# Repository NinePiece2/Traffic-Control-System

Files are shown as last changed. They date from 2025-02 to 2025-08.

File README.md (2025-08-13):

# **Traffic Control System** 🚦  

## Table of Contents
- [**Traffic Control System** 🚦](#traffic-control-system-)
  - [Table of Contents](#table-of-contents)
  - [Workflow Status](#workflow-status)
  - [Introduction \& Background](#introduction--background)
    - [Background](#background)
    - [Rationale](#rationale)
    - [Scope](#scope)
  - [Design Specifications](#design-specifications)
    - [Pedestrian Detection and Safety](#pedestrian-detection-and-safety)
    - [Real-Time Video Streaming](#real-time-video-streaming)
    - [Hand Drawn Schematic of the Physical Design](#hand-drawn-schematic-of-the-physical-design)
    - [Microservice Architecture Design Diagram](#microservice-architecture-design-diagram)
    - [Early Design Mockup](#early-design-mockup)
    - [Final Design Implementation](#final-design-implementation)
      - [User Login](#user-login)
      - [Available Signals](#available-signals)
      - [Incident Reports for a Traffic Light](#incident-reports-for-a-traffic-light)
      - [Live Traffic Light](#live-traffic-light)
      - [Accounts Page](#accounts-page)
    - [Physical Design Components](#physical-design-components)
      - [PCB Design Image](#pcb-design-image)
      - [Design Assembly Render](#design-assembly-render)
      - [Design Assembly Render Video](#design-assembly-render-video)
      - [Physical Design Photo](#physical-design-photo)
  - [Installing the Microservices](#installing-the-microservices)
  - [Client Install Instructions:](#client-install-instructions)
    - [Client Debugging](#client-debugging)

## Workflow Status

| Workflow | Status |
|---|---|
| CI MVC Application | |
| CI API Application |  |
| CI Video Application |  |
| CD MVC, API, and Video Applications |  |
| Client CI Pipeline |  |

## Introduction & Background

A **smart traffic control system** designed to efficiently manage and optimize traffic flow.

### Background
In the modern day, successfully controlling urban traffic in the city is a necessity due to the ever-increasing number of vehicles and, consequently, the need for pedestrian safety.  In considering the traffic control system, what comes to mind is its ability to handle complex, changing traffic conditions, communicate clearly, and be accessible to visually impaired pedestrians. Additionally, incorporating sophisticated monitoring and control features into these systems continues to pose a technical challenge.

A frequent drawback in previous designs was the dependence on RF-link communication, which imposed limitations regarding data transmission reliability and scalability. To overcome these limitations, this project shifts to utilizing WiFi communication, providing increased flexibility, greater bandwidth, and improved compatibility with contemporary web-oriented control systems.

### Rationale
When determining the core processing unit, the Raspberry Pi was selected with the vision of being capable of employing adaptable and affordable embedded systems. Some of the benefits of the Raspberry Pi include real-time data processing, streamlined integration with cameras and sensors, and effective communication through WiFi. This makes it a perfect option for projects that need both hardware management and software interaction.

The web technologies were chosen to offer an intuitive user interface for system supervision and management. A .NET MVC website was created, incorporating Microsoft Identity Framework for secure user login, allowing the traffic system managers to have remote access to the system. As a result, supervisors can easily change parameters, manually control traffic signals, and view stored camera data such as images and videos of traffic violations. The addition of video imaging features improves the dependability of the system by allowing for future footage examination, holding violators accountable.

### Scope
The prototype created in this project tackles essential elements of traffic management by emphasizing real-time regulation and accessibility components. The system comprises:

1.	Real-Time Traffic Management: Combining magnetic reed switches and pedestrian buttons enables adaptive modification of traffic signals according to the presence of vehicles and pedestrians.
2.	Pedestrian Support: Buttons to signal a pedestrian to cross safely. Additionally, chimes at the time of safe crossing to signal the visually impaired are included.
3.	Traffic Violation Surveillance: A CMOS camera records high-quality images of traffic infractions, with video recording capabilities available for immediate processing and storage.
4.	Remote Management: A prototype website, developed using .NET MVC, allows for secure manual traffic light operations and remote observation of violation information.

This project provides a scalable solution for traffic control issues by incorporating contemporary technologies and enhancing traditional models. Future versions can upgrade the system’s capabilities to incorporate sophisticated image recognition, cloud storage, and overall traffic management across the network.

---

## Design Specifications

The Traffic Light Control System is designed to improve traffic management and pedestrian safety while addressing modern urban mobility challenges. The system provides:
-	Accessibility for Visually Impaired Pedestrians: Auditory signals inform visually impaired individuals when it is safe to cross the street.
-	Traffic Violation Detection: The Traffic Light Control System uses pressure sensors in order to detect when a vehicle crosses an intersection under a red light. It also uses a camera to take a picture of the violator's license plate, and record it for further use.
-	Remote Control and Data Access: The system uses a user friendly GUI, which, when connected to the internet, allows for monitoring the intersection at real time. Other features include recording and storing violations, and also manually adjusting the lights using an override.
-	Operation Modes: The user can change  traffic signal timings in accordance to different times of the day. this is useful for when there is an unexpected scenario, or an increase or decrease in traffic.
-	Power and Processing Requirements: A 5V power supply supports a Raspberry Pi single-board computer. The Raspberry Pi's integrated GPIO pins are used to interface with sensors, cameras, and traffic signal components, making it a very easy to use platform for this application.

### Pedestrian Detection and Safety

The SSD-MobileNetV2-FPNLite model is used to properly identify and classify pedestrians, vehicles and other objects. Pytesseract is used to extract license plates from vehicles that have commited traffic violations. For pedestrian safety, buzzers are used to sound for when there is a traffic violation detected, which is used alongside a pressure sensor. Lastly, other audio beeps are used for when a pedestrian requests to cross, and then they are sounded to make both the pedestrian and driver alerted of the shortened signal timings.

### Real-Time Video Streaming

RTMP ensures smooth video streaming from the CMOS camera to the GUI. This allows the user to be able to control traffic remotely, and make any changes necessary. They can also monitor the live intersection, and look at recorded traffic violations, should they deem necessary.

### Hand Drawn Schematic of the Physical Design

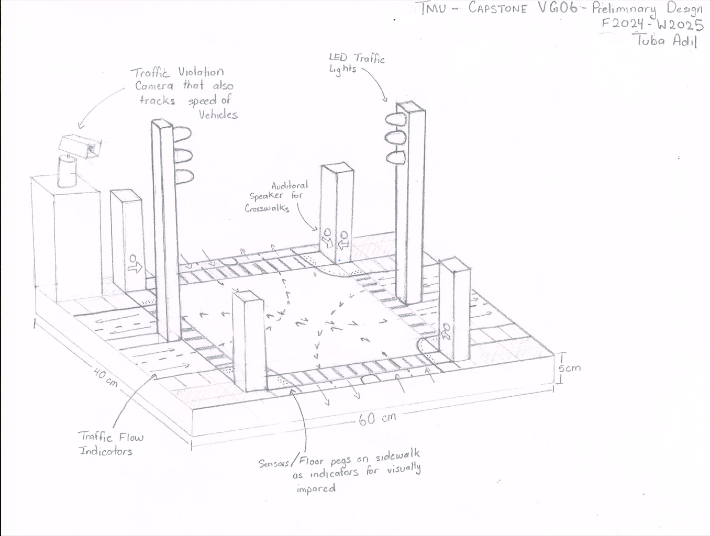
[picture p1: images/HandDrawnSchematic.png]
[](images/HandDrawnSchematic.png)

### Microservice Architecture Design Diagram

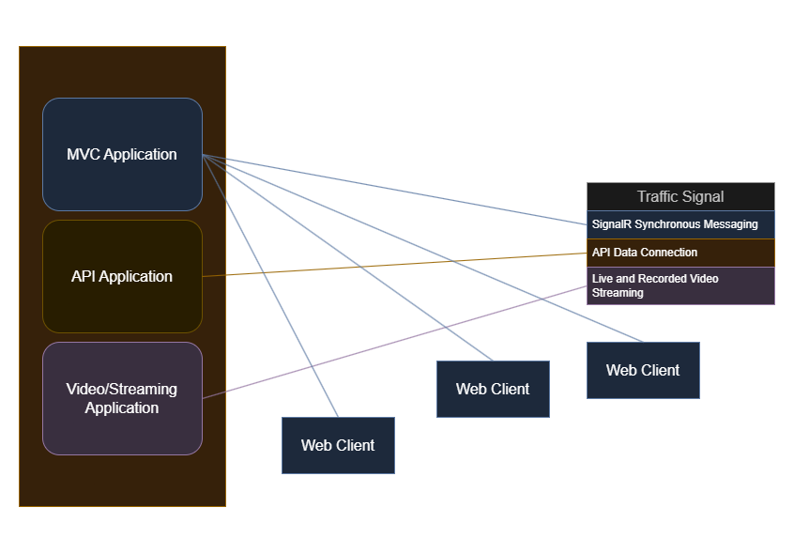
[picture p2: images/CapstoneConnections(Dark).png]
[](images/CapstoneConnections(Dark).png)

### Early Design Mockup

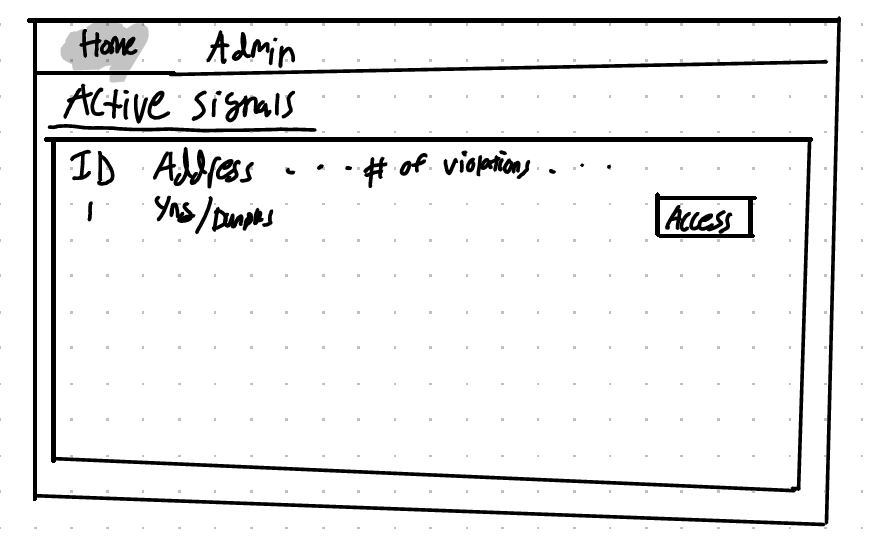
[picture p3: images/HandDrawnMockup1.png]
[](images/HandDrawnMockup1.png)
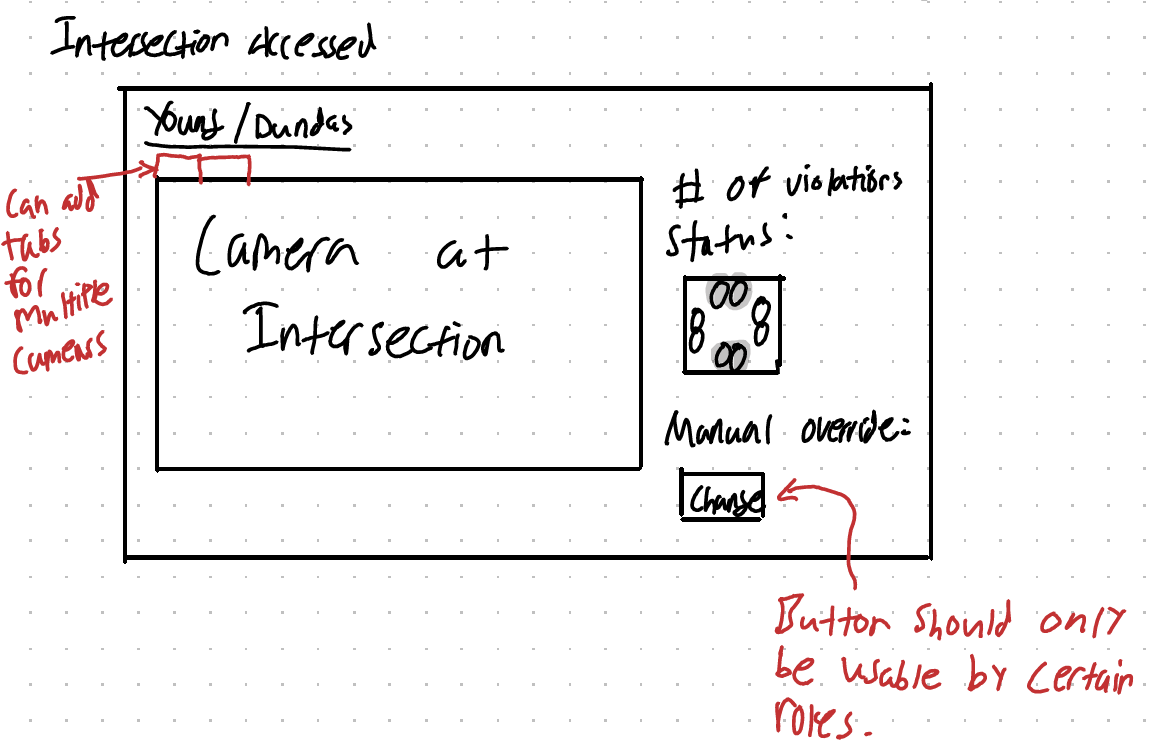
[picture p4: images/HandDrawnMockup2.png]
[](images/HandDrawnMockup2.png)

### Final Design Implementation

#### User Login 

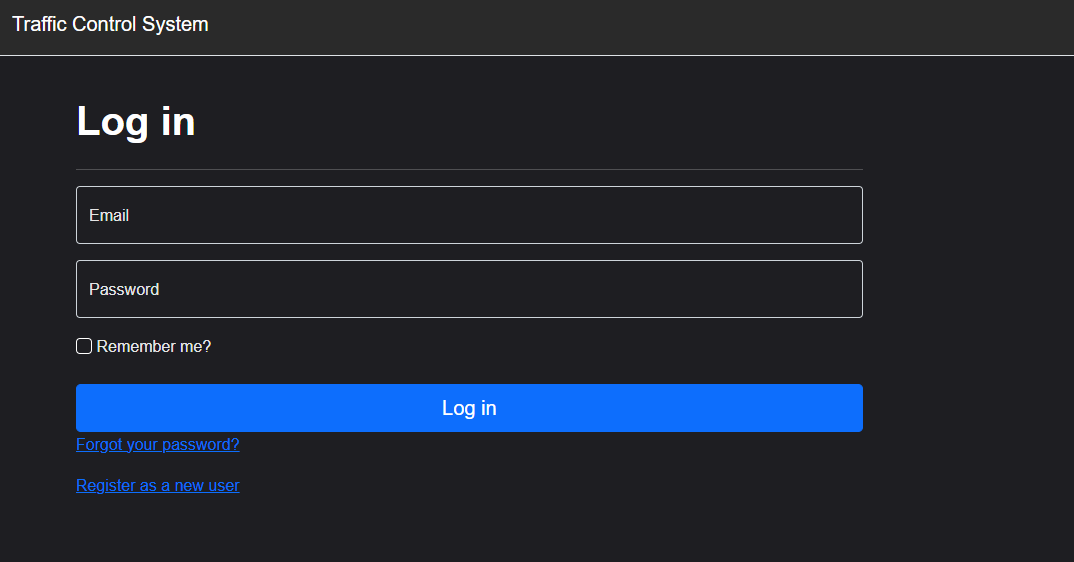
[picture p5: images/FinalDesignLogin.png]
[](images/FinalDesignLogin.png)

#### Available Signals

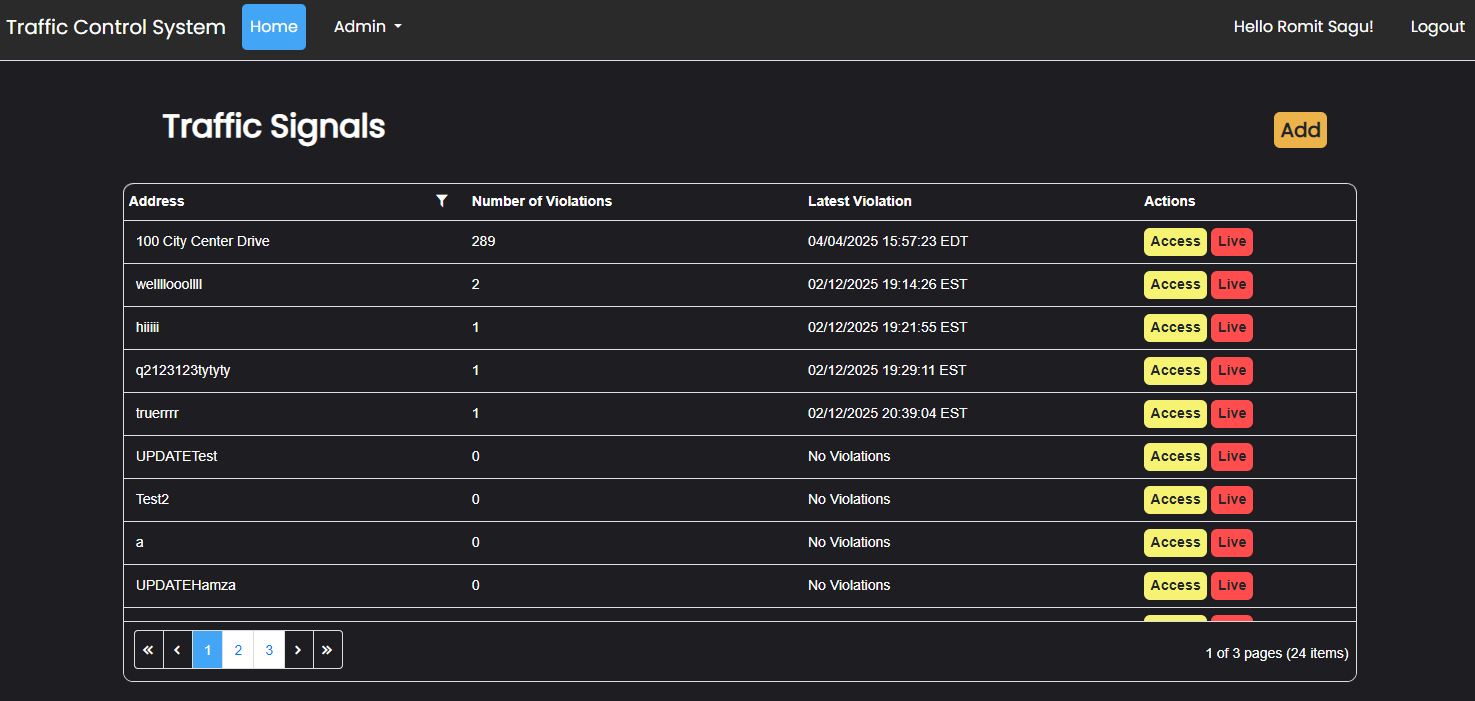
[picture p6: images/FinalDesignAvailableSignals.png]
[](images/FinalDesignAvailableSignals.png)

#### Incident Reports for a Traffic Light

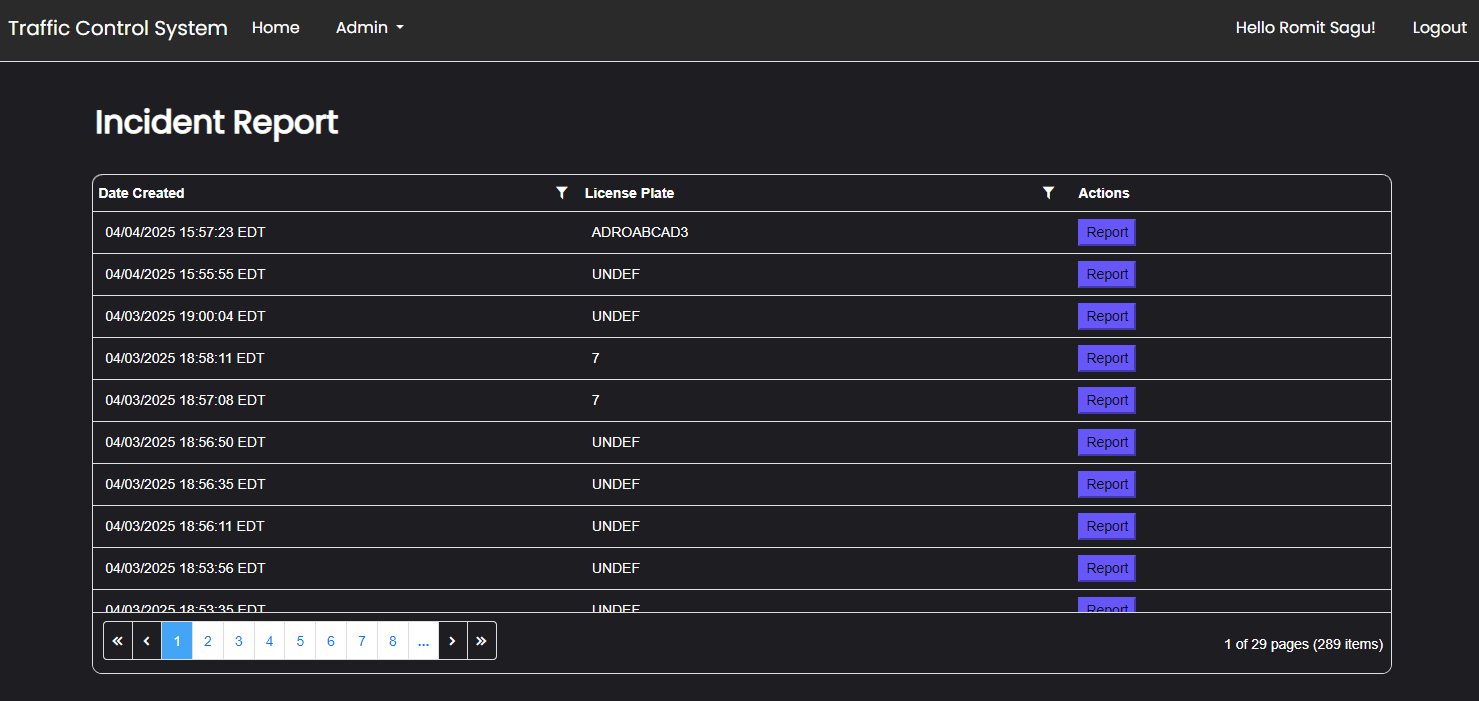
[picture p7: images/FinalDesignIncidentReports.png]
[](images/FinalDesignIncidentReports.png)

#### Live Traffic Light

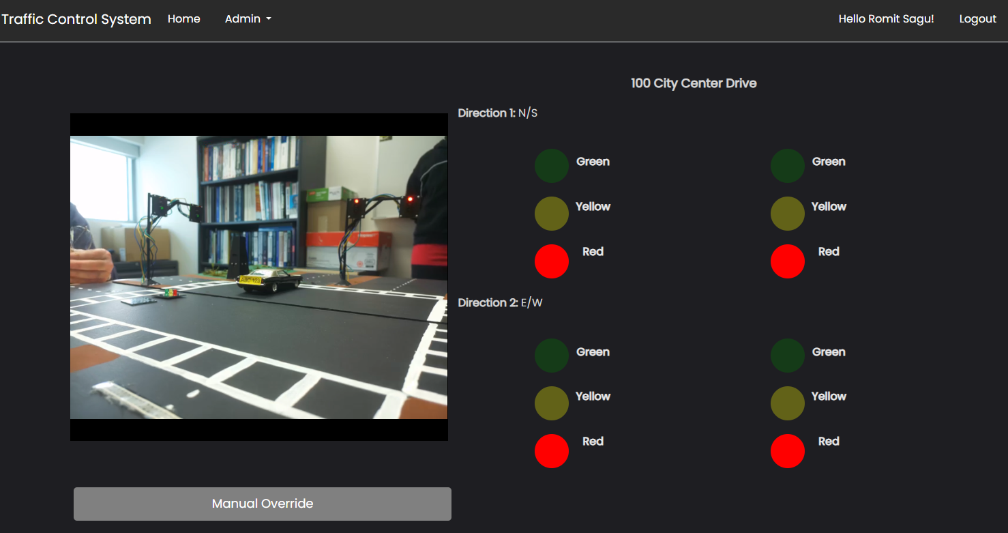
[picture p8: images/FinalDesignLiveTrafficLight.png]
[](images/FinalDesignLiveTrafficLight.png)

#### Accounts Page

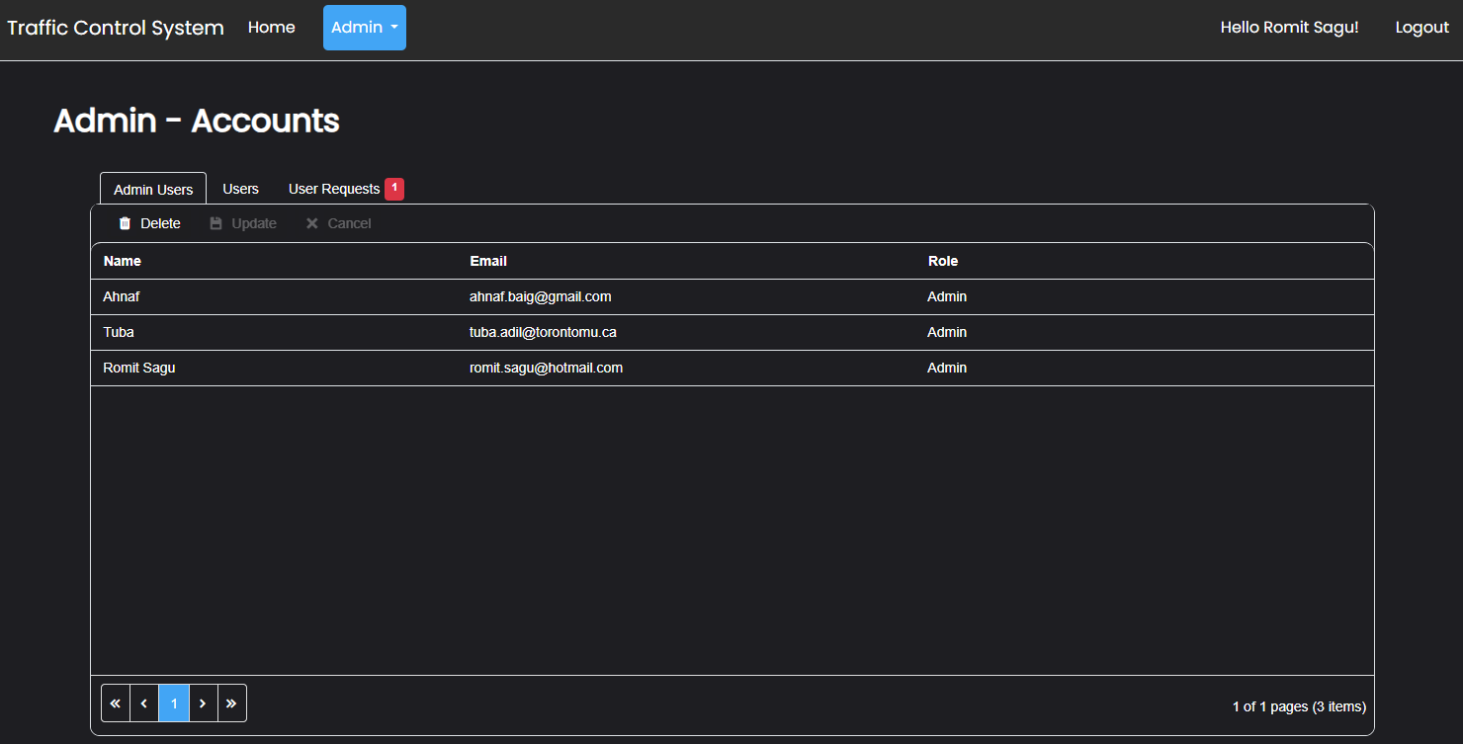
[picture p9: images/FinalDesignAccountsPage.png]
[](images/FinalDesignAccountsPage.png)

### Physical Design Components

To make the physical design look cohesive, a custom Printed Circut Board was designed and manufactured to replicate an actual traffic light. The CAD and PCB design files are availabe <a href="https://github.com/NinePiece2/Traffic-Control-System/tree/master/CADFiles" target="_blank" rel="noopener noreferrer">here</a>. The CAD files were designed using Fusion 360 and the PCB was created using KiCAD.

#### PCB Design Image

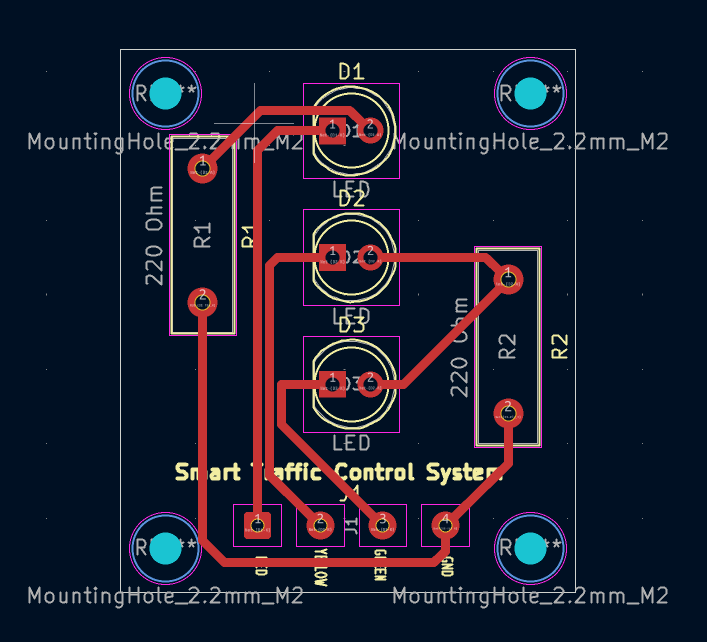
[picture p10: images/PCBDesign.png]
[](images/PCBDesign.png)

#### Design Assembly Render

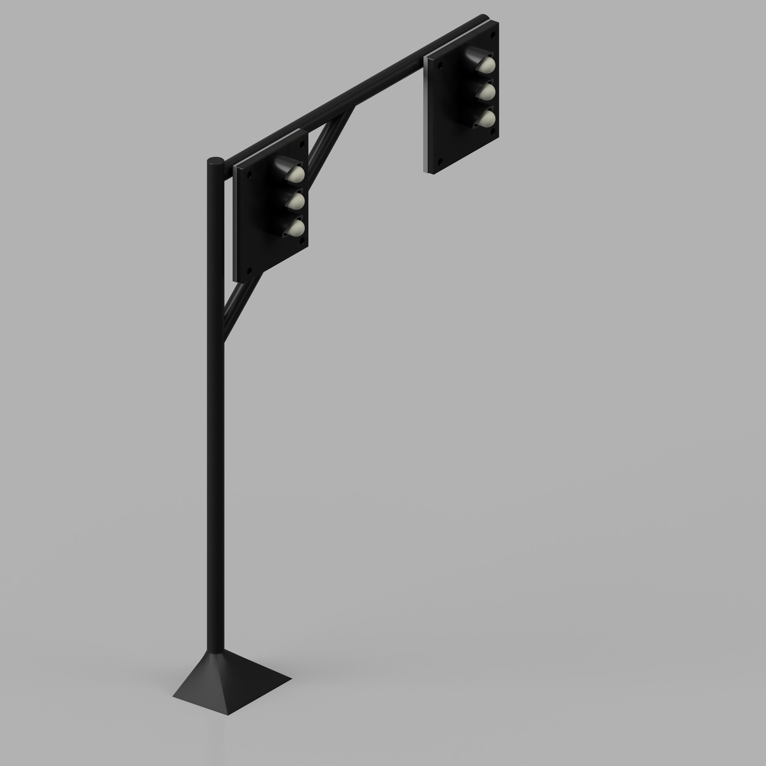
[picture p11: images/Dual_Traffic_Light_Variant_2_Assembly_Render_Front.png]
[](images/Dual_Traffic_Light_Variant_2_Assembly_Render_Front.png)

#### Design Assembly Render Video

<!-- <video src="images/Dual_Traffic_Light_Variant_2_Assembly_Render_v3_Animation_2.mp4" autoplay muted loop playsinline width="800"></video> -->

Click to download the video:

<a href="https://github.com/NinePiece2/Traffic-Control-System/raw/refs/heads/master/images/Dual_Traffic_Light_Variant_2_Assembly_Render_v3_Animation_2.mp4">
  Video Preview
</a>

#### Physical Design Photo

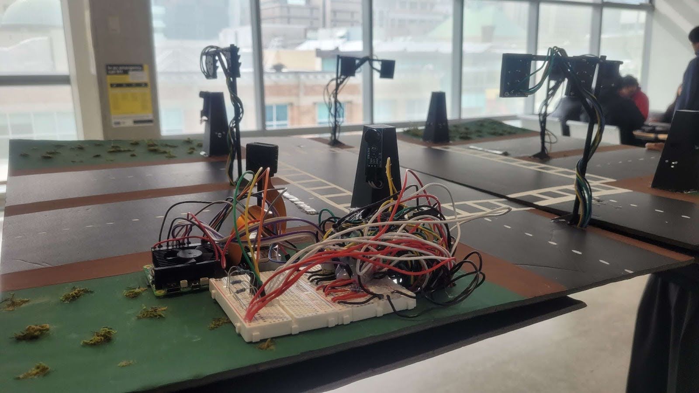
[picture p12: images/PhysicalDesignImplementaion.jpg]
[](images/PhysicalDesignImplementaion.jpg)

---

## Installing the Microservices

Use ```docker-compose.yml``` and change the variables where applicable to allow the microservices to communicate with each other. Use SSL certificates as required. The `JWT_KEY` should be the same on all the services.

```docker-compose.yml```:

```yml
version: '3.8'

services:
  mvc:
    image: ninepiece2/traffic-control-system:mvc
    container_name: Traffic-Control-System
    ports:
      - "8443:8443"
    volumes:
      - /root/certs:/https:ro
    environment:
      - ASPNETCORE_URLS=https://*:8443;http://*:8080
      - ASPNETCORE_Kestrel__Certificates__Default__Path=/https/ssl.crt
      - ASPNETCORE_Kestrel__Certificates__Default__KeyPath=/https/ssl.key
      - ASPNETCORE_ENVIRONMENT=${ASPNETCORE_ENVIRONMENT}
      - SyncfusionLicense=${SyncfusionLicense}
      - BaseUrl=https://trafficcontrolsystem.romitsagu.com
      - VideoServiceURL=https://stream-trafficcontrolsystem.romitsagu.com
      - StreamServiceURL=https://stream1-trafficcontrolsystem.romitsagu.com
      - APIURL=https://api-trafficcontrolsystem.romitsagu.com
      - API_KEY=${JWT_Key}
    command: ["dotnet", "Traffic-Control-System.dll"]
    restart: always
  
  api:
    image: ninepiece2/traffic-control-system:api
    container_name: Traffic-Control-System-API
    ports:
      - "8445:8445"
    volumes:
      - /root/certs:/https:ro
    environment:
      - ASPNETCORE_URLS=https://*:8445;http://*:8080
      - ASPNETCORE_Kestrel__Certificates__Default__Path=/https/ssl.crt
      - ASPNETCORE_Kestrel__Certificates__Default__KeyPath=/https/ssl.key
      - ASPNETCORE_ENVIRONMENT=${ASPNETCORE_ENVIRONMENT}
      - StreamServiceURL=https://stream1-trafficcontrolsystem.romitsagu.com
      - JWT:Issuer=https://api-trafficcontrolsystem.romitsagu.com
      - JWT:Audience=https://api-trafficcontrolsystem.romitsagu.com
      - JWT:Key=${JWT_Key}
    command: ["dotnet", "Traffic-Control-System-API.dll"]
    restart: always

  video:
    image: ninepiece2/traffic-control-system:video
    container_name: Traffic-Control-System-Video
    ports:
      - "1935:1935"
      - "8446:8446"
    volumes:
      - /root/certs:/https:ro
    environment:
      - ASPNETCORE_URLS=https://*:8446;http://*:8080
      - ASPNETCORE_Kestrel__Certificates__Default__Path=/https/ssl.crt
      - ASPNETCORE_Kestrel__Certificates__Default__KeyPath=/https/ssl.key
      - ASPNETCORE_ENVIRONMENT=${ASPNETCORE_ENVIRONMENT}
      - JWT:Issuer=https://stream-trafficcontrolsystem.romitsagu.com
      - JWT:Audience=https://stream-trafficcontrolsystem.romitsagu.com
      - JWT:Key=${JWT_Key}
    command: ["dotnet", "Traffic-Control-System-Video.dll"]
    restart: always
```

## Client Install Instructions:

Run the following on a Raspberry Pi 5. This will install docker, docker compose and create a new folder with the ```docker-compose.yml``` file and a config file located under ```config/config.json```. After creating a new traffic light in the MVC application enter the outputed config values in the ```config/config.json``` file. Follow the instructions and run ```docker compose up -d```/```docker-compose up -d``` within the created folder to run the container and traffic light application.

```sh
curl -O https://raw.githubusercontent.com/NinePiece2/Traffic-Control-System/refs/heads/master/RaspPiPythonScripts/installer.sh && sudo bash installer.sh
```

### Client Debugging

If you enconuter:

```sh
OSError: [Errno 12] Cannot allocate memory
```

Go to the file `sudo nano /boot/firmware/config.txt`

Locate the line `dtoverlay=vc4-fkms-v3d` and change it to `dtoverlay=vc4-fkms-v3d,cma-256` and Restart the Raspberry Pi.

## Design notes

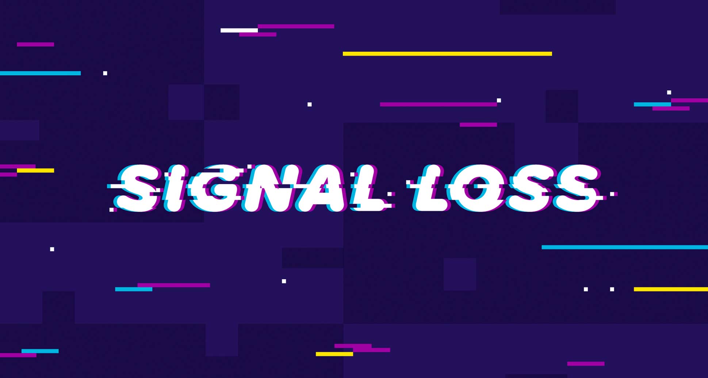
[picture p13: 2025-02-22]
Traffic-Control-System/wwwroot/Images/error-placeholder.jpg

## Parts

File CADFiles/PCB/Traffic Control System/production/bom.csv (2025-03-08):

Designator | Footprint | Quantity | Value | LCSC Part #
D1, D2, D3 | LED_D5.0mm_Clear | 3 | LED
J1 | SolderWire-0.25sqmm_1x04_P4.2mm_D0.65mm_OD1.7mm | 1 | Conn_01x04_Pin
R1, R2 | R_Box_L13.0mm_W4.0mm_P9.00mm | 2 | 220 Ohm

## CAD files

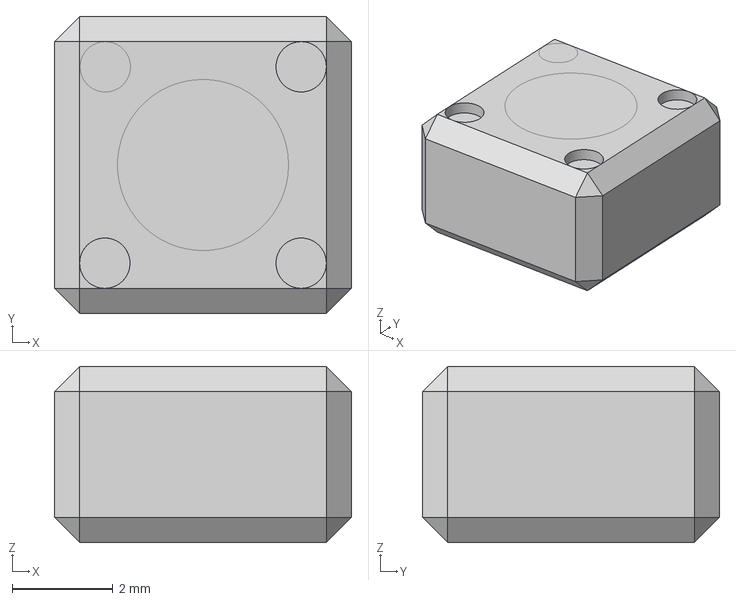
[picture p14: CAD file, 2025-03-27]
CADFiles/3D Printed Mounts/Traffic Light Button Hole v4.step
5.90 x 5.90 x 3.50 mm

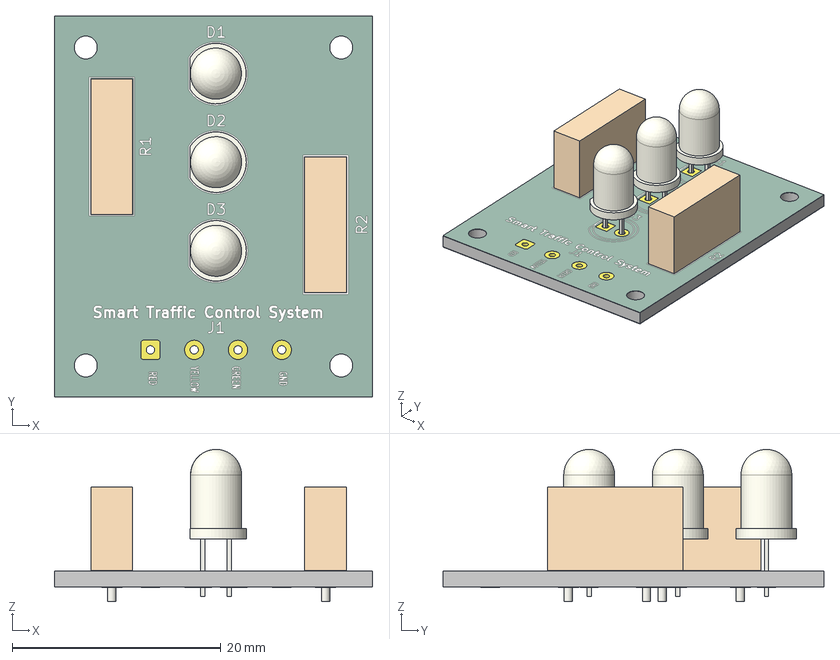
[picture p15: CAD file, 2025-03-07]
CADFiles/PCB/Traffic Control System/Traffic Control System.step
30.5 x 36.5 x 14.6 mm
R_Box_L13.0mm_W4.0mm_P9.00mm x 2
LED_D5.0mm_Clear x 3
Traffic Control System_copper
Traffic Control System_silkscreen
Traffic Control System_soldermask
Traffic Control System_PCB

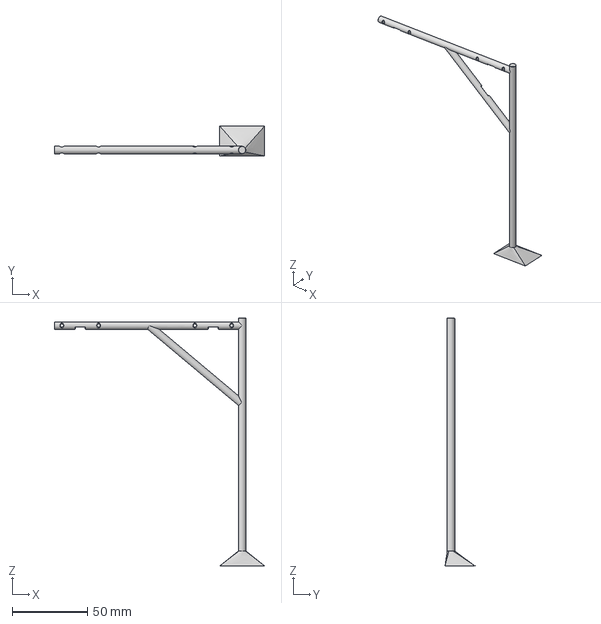
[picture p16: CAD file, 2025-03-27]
CADFiles/3D Printed Mounts/Dual Traffic Light Variant 2 v9.step
140.0 x 20.0 x 165.0 mm

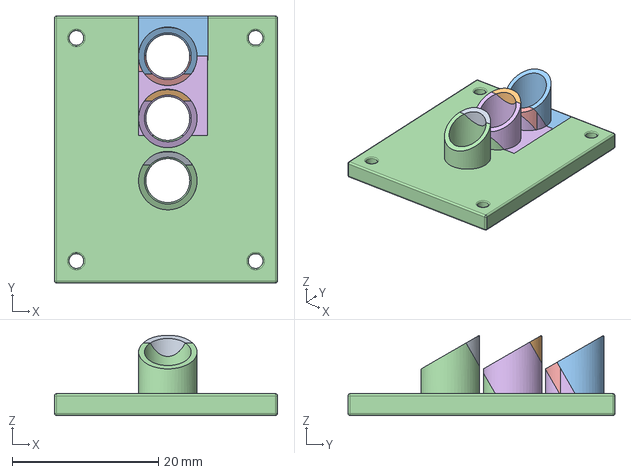
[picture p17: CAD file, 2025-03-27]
CADFiles/3D Printed Mounts/Traffic Light Cover v9.step
30.5 x 36.5 x 11.0 mm

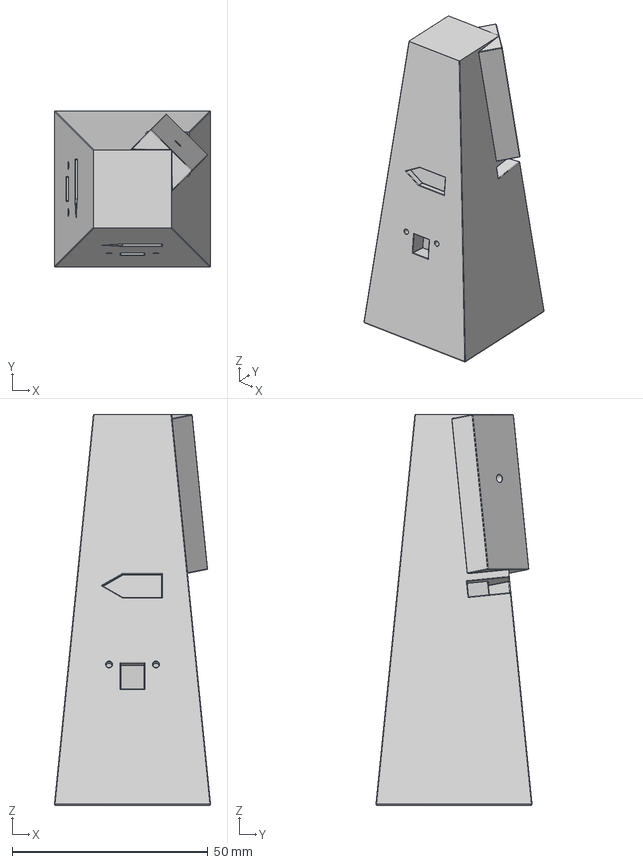
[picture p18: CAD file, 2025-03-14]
CADFiles/3D Printed Mounts/Button and Buzzer stand.step
39.9 x 39.9 x 100.0 mm

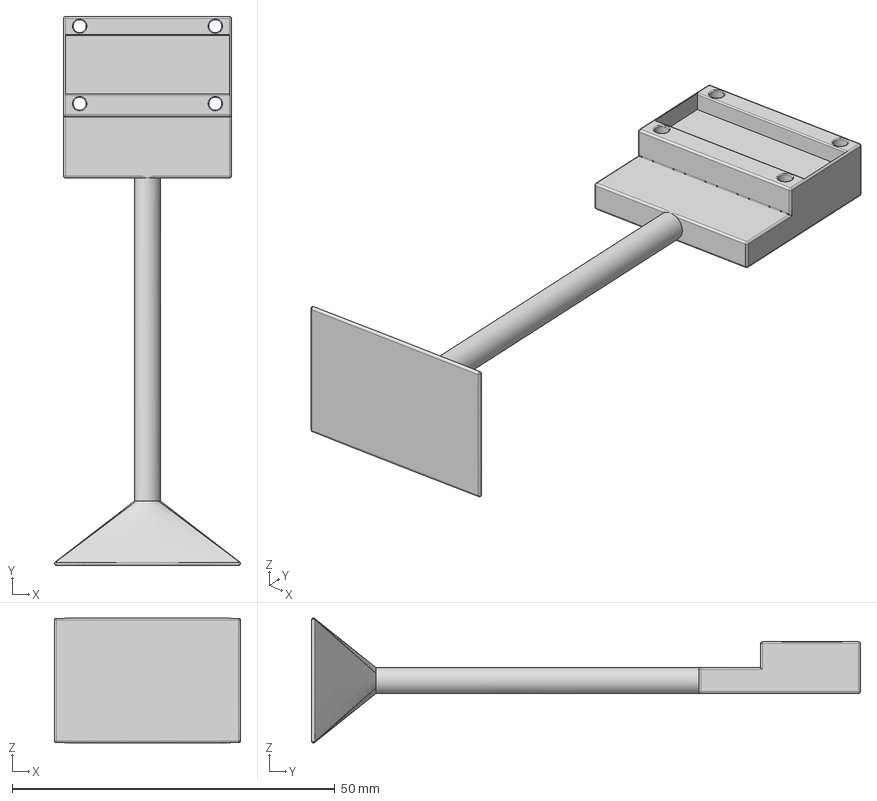
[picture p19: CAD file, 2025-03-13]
CADFiles/3D Printed Mounts/Pi AI Camera Stand.step
28.8 x 85.0 x 19.3 mm

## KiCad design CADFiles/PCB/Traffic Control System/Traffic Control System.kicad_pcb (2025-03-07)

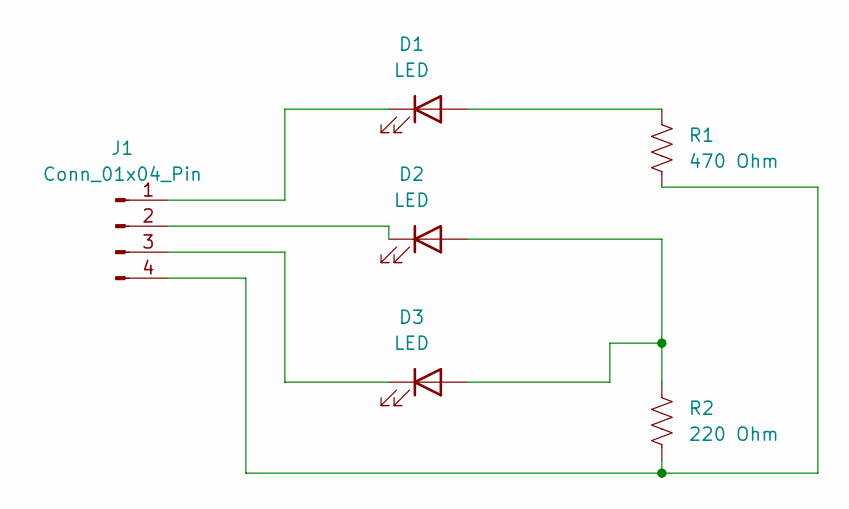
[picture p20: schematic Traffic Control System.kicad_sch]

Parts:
D1, D2, D3: LED; LED_D5.0mm_Clear
J1: Conn_01x04_Pin; SolderWire-0.25sqmm_1x04_P4.2mm_D0.65mm_OD1.7mm
R1: 470 Ohm; R_Box_L13.0mm_W4.0mm_P9.00mm
R2: 220 Ohm; R_Box_L13.0mm_W4.0mm_P9.00mm

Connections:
unnamed: D1.2 (A), R1.1
unnamed: D1.1 (K), J1.1
unnamed: D2.2 (A), D3.2 (A), R2.1
unnamed: D2.1 (K), J1.2
unnamed: D3.1 (K), J1.3
unnamed: J1.4, R1.2, R2.2

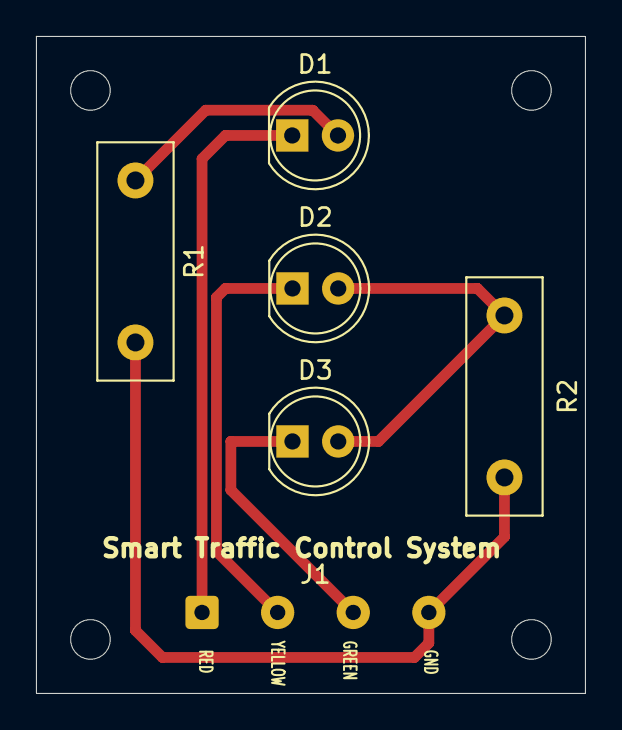
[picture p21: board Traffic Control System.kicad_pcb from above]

Board: 2 copper layers, 30.5 x 36.5 mm, 6 parts (0 on the bottom side), 6 nets.

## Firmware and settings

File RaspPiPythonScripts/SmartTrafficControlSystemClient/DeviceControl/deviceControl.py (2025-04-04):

import os
import platform
import time
import threading
from gpiozero import LED, Button, PWMOutputDevice
import Config.config as config
import threading

# Only set the mock pin factory if the OS is not Linux
if platform.system() != "Linux":
    os.environ["GPIOZERO_PIN_FACTORY"] = "mock"
    print("DEV DETECTED: Using mock pin factory")
else:
    print("PROD: Using RPi pin factory")


class TrafficLightController:
    def __init__(self, signalR_client_callback, incident_detected_callback):
        """
        Initializes the traffic light controller with configuration.
        """
        self.interrupt_flag = threading.Event()
        self.signalR_client_callback = signalR_client_callback
        self.incident_detected_callback = incident_detected_callback

        # Define traffic lights for two directions
        self.traffic_lights = {
            "light_dir_1": {"red": LED(17), "yellow": LED(27), "green": LED(22)},
            "light_dir_2": {"red": LED(23), "yellow": LED(24), "green": LED(25)}
        }

        # Define pedestrian buttons (One per direction)
        self.pedestrian_buttons = {
            "light_dir_1": Button(18),  # GPIO 18 for direction 1
            "light_dir_2": Button(19)   # GPIO 19 for direction 2
        }

        # Attach event listeners for pedestrian buttons
        self.pedestrian_buttons["light_dir_1"].when_pressed = lambda: self.pedestrian_pressed("light_dir_1")
        self.pedestrian_buttons["light_dir_2"].when_pressed = lambda: self.pedestrian_pressed("light_dir_2")

        self.pedestrian_button_pressed = {
            "light_dir_1": False,
            "light_dir_2": False
        }

        # Define passive buzzers on pins 12, 13, 14, and 15 using PWMOutputDevice (Buzzers need to be attached to 3.3v)
        self.buzzers = {
            "buzzer1": PWMOutputDevice(12, active_high=False),
            # "buzzer2": PWMOutputDevice(13, active_high=False),
            # "buzzer3": PWMOutputDevice(14, active_high=False),
            # "buzzer4": PWMOutputDevice(15, active_high=False)
        }

        self.pressure_sensors = {
            "light_dir_1_sensor1": Button(5),
            "light_dir_1_sensor2": Button(6),
            "light_dir_2_sensor1": Button(13),
            "light_dir_2_sensor2": Button(16)
        }

        self.last_pressure_detected = {
            "light_dir_1_sensor1": time.mktime((1970, 1, 1, 0, 0, 0, 0, 1, -1)),
            "light_dir_1_sensor2": time.mktime((1970, 1, 1, 0, 0, 0, 0, 1, -1)),
            "light_dir_2_sensor1": time.mktime((1970, 1, 1, 0, 0, 0, 0, 1, -1)),
            "light_dir_2_sensor2": time.mktime((1970, 1, 1, 0, 0, 0, 0, 1, -1))
        }

        self.last_pressure_release_detected = {
            "light_dir_1_sensor1": time.mktime((1970, 1, 1, 0, 0, 0, 0, 1, -1)),
            "light_dir_1_sensor2": time.mktime((1970, 1, 1, 0, 0, 0, 0, 1, -1)),
            "light_dir_2_sensor1": time.mktime((1970, 1, 1, 0, 0, 0, 0, 1, -1)),
            "light_dir_2_sensor2": time.mktime((1970, 1, 1, 0, 0, 0, 0, 1, -1))
        }

        self.pressure_sensors["light_dir_1_sensor1"].when_released = lambda: self.pressure_sensor_pressed("light_dir_1_sensor1")
        self.pressure_sensors["light_dir_1_sensor2"].when_released = lambda: self.pressure_sensor_pressed("light_dir_1_sensor2")
        self.pressure_sensors["light_dir_2_sensor1"].when_released = lambda: self.pressure_sensor_pressed("light_dir_2_sensor1")
        self.pressure_sensors["light_dir_2_sensor2"].when_released = lambda: self.pressure_sensor_pressed("light_dir_2_sensor2")

        self.pressure_sensors["light_dir_1_sensor1"].when_held = lambda: self.pressure_sensor_released("light_dir_1_sensor1")
        self.pressure_sensors["light_dir_1_sensor2"].when_held = lambda: self.pressure_sensor_released("light_dir_1_sensor2")
        self.pressure_sensors["light_dir_2_sensor1"].when_held = lambda: self.pressure_sensor_released("light_dir_2_sensor1")
        self.pressure_sensors["light_dir_2_sensor2"].when_held = lambda: self.pressure_sensor_released("light_dir_2_sensor2")

        # Track active light (default direction)
        self.active_light = "light_dir_1"

    def pedestrian_pressed(self, light_name):
        """Handles pedestrian button press event for the given direction."""
        self.pedestrian_button_pressed[light_name] = True
    
    def pressure_sensor_pressed(self, sensor_name):
        """Handles pressure sensor press event for the given sensor."""
        self.last_pressure_detected[sensor_name] = time.time()
        #print(f"Pressure sensor {sensor_name} pressed {time.strftime('%Y-%m-%d %H:%M:%S', time.localtime(time.time()))}.")

    def pressure_sensor_released(self, sensor_name):
        """Handles pressure sensor release event for the given sensor."""
        self.last_pressure_release_detected[sensor_name] = time.time()
        #print(f"Pressure sensor {sensor_name} released {time.strftime('%Y-%m-%d %H:%M:%S', time.localtime(time.time()))}.")

    def update_config(self):
        """Updates the config dynamically and interrupts the current cycle."""
        self.interrupt_flag.set()

    def manual_override(self):
        """Triggers a manual override, stopping the current cycle immediately."""
        self.interrupt_flag.set()

    def switch_light(self, light_name, color):
        """Controls the lights (green, yellow, red) based on the given color."""
        light = self.traffic_lights[light_name]
        if color == "green":
            light["red"].off()
            light["yellow"].off()
            light["green"].on()
        elif color == "yellow":
            light["green"].off()
            light["yellow"].on()
            light["red"].off()
        elif color == "red":
            light["yellow"].off()
            light["red"].on()
            light["green"].off()
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

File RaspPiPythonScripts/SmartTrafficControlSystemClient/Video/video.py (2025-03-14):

import cv2
import subprocess
import threading
import time
from collections import deque
import requests
import Config.config as config
from jwt.exceptions import DecodeError
from datetime import datetime, timezone
import urllib.parse
import jwt
import platform
import numpy as np
import pytesseract  # For OCR
import re
import os
# Optional: if Tesseract is not in your PATH, set the tesseract_cmd
# pytesseract.pytesseract.tesseract_cmd = r"/usr/bin/tesseract"  # Adjust as needed

# Attempt to import Picamera2 and IMX500-related modules on Linux
try:
    if platform.system() == 'Linux':
        from picamera2 import Picamera2, MappedArray
        try:
            from picamera2.devices import IMX500
            from picamera2.devices.imx500 import NetworkIntrinsics, postprocess_nanodet_detection
        except ImportError:
            IMX500 = None
except ImportError:
    pass

# Global variable for detections
last_detections = []

# ----- IMX500 Object Detection Helpers -----
class Detection:
    def __init__(self, coords, category, conf, metadata, picam2, imx500_obj):
        """Stores the detection bounding box, category and confidence.
           Uses the imx500 helper to convert raw coordinates into pixel coordinates.
        """
        self.category = category
        self.conf = conf
        # Convert inference coordinates into pixel coordinates on the output image
        self.box = imx500_obj.convert_inference_coords(coords, metadata, picam2)

def parse_detections(metadata, picam2, imx500_obj, threshold, iou, max_detections):
    """Parses the raw outputs from the IMX500 detector into Detection objects."""
    global last_detections
    intrinsics = imx500_obj.network_intrinsics
    bbox_normalization = getattr(intrinsics, 'bbox_normalization', False)
    bbox_order = getattr(intrinsics, 'bbox_order', 'yx')  # default order
    np_outputs = imx500_obj.get_outputs(metadata, add_batch=True)
    input_w, input_h = imx500_obj.get_input_size()
    if np_outputs is None:
        return last_detections
    # Use nanodet postprocessing if specified
    if getattr(intrinsics, 'postprocess', None) == "nanodet":
        boxes, scores, classes = postprocess_nanodet_detection(
            outputs=np_outputs[0],
            conf=threshold,
            iou_thres=iou,
            max_out_dets=max_detections
        )[0]
        from picamera2.devices.imx500.postprocess import scale_boxes
        boxes = scale_boxes(boxes, 1, 1, input_h, input_w, False, False)
    else:
        boxes, scores, classes = np_outputs[0][0], np_outputs[1][0], np_outputs[2][0]
        if bbox_normalization:
            boxes = boxes / input_h
        if bbox_order == "xy":
            boxes = boxes[:, [1, 0, 3, 2]]
        boxes = np.array_split(boxes, 4, axis=1)
        boxes = list(zip(*boxes))
    detections = [
        Detection(box, int(category), float(score), metadata, picam2, imx500_obj)
        for box, score, category in zip(boxes, scores, classes)
        if score > threshold
    ]
    last_detections = detections
    return detections

def get_labels(intrinsics):
    """Returns a list of labels from intrinsics. Falls back to a default file if needed."""
    labels = intrinsics.labels
    if labels is None:
        try:
            with open("assets/coco_labels.txt", "r") as f:
                labels = f.read().splitlines()
        except Exception as e:
            print("Error loading default labels:", e)
            labels = []
    return labels

def recognize_license_plate(car_roi):
    """
    Given a region-of-interest (ROI) containing a car,
    locate and OCR the license plate assuming it has a YELLOW background.
    """
    # Convert the ROI to HSV color space
    hsv = cv2.cvtColor(car_roi, cv2.COLOR_BGR2HSV)

    # Define HSV range for yellow plates (tweak values as needed)
    lower_yellow = np.array([20, 100, 100], dtype=np.uint8)
    upper_yellow = np.array([35, 255, 255], dtype=np.uint8)
    
    # Create a mask that isolates only yellow regions
    mask = cv2.inRange(hsv, lower_yellow, upper_yellow)

    # Optional: Clean up the mask using morphological operations
    kernel = cv2.getStructuringElement(cv2.MORPH_RECT, (3, 3))
    mask = cv2.erode(mask, kernel, iterations=1)
    mask = cv2.dilate(mask, kernel, iterations=1)
    
    # Find contours in the mask
    contours, _ = cv2.findContours(mask, cv2.RETR_EXTERNAL, cv2.CHAIN_APPROX_SIMPLE)
    if not contours:
        return None, None

    # Sort contours by area (largest first)
    contours = sorted(contours, key=cv2.contourArea, reverse=True)
    
    # We�ll iterate through the biggest contours to find something
    # that looks like a plate by aspect ratio, etc.
    plate_candidate = None
    plate_bbox = None
    
    for c in contours:
        x, y, w, h = cv2.boundingRect(c)
        area = w * h
        aspect_ratio = w / float(h + 1e-5)  # avoid divide-by-zero
        # Heuristic checks (tweak thresholds for your plate shape/size)
        if area > 500:  # minimum area
            # For typical rectangular plates, aspect ratio often 2�5 wide
            if 2 < aspect_ratio < 6:  
                plate_candidate = car_roi[y:y+h, x:x+w]
                plate_bbox = (x, y, w, h)
                break  # pick the first (largest) plausible region
    
    if plate_candidate is None:
        return None, None

    # ---- Preprocess the plate region for OCR ----
    # Convert to grayscale
    gray_plate = cv2.cvtColor(plate_candidate, cv2.COLOR_BGR2GRAY)

    # Upscale to enhance details
    gray_plate = cv2.resize(gray_plate, None, fx=3, fy=3, interpolation=cv2.INTER_CUBIC)

    # Try adaptive threshold
    gray_plate = cv2.adaptiveThreshold(
        gray_plate, 255,
        cv2.ADAPTIVE_THRESH_GAUSSIAN_C,
        cv2.THRESH_BINARY,
        11, 2
    )

    # Dilation to help join character segments
    gray_plate = cv2.dilate(gray_plate, kernel, iterations=1)

    # OCR with Tesseract
    config_tesseract = "--oem 3 --psm 6 -c tessedit_char_whitelist=ABCDEFGHIJKLMNOPQRSTUVWXYZ0123456789"
    text = pytesseract.image_to_string(gray_plate, config=config_tesseract).strip()

    # Clean up the OCR result: remove extra whitespace, uppercase
    text = "".join(text.split()).upper()

    return text, plate_bbox
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

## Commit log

2024-10-09 Add PowerSettings
2024-10-27 try to fix framerate
2024-10-27 Try to fix framerate issues
2025-01-31 Try to fix webcam issue
    [video.py]
2025-01-31 Try to fix FFMpeg issue
    [video.py]
2025-02-02 Small Update [skip ci]
    [video.py]
2025-02-17 Add YOLO
    [yolov3-tiny.cfg]
2025-02-17 Add IMX500 Object Detection and Test CI
    [yolov3-tiny.cfg]
2025-02-17 Fix video format issue [skip ci]
    [video.py]
2025-02-18 Add License Plate Detection
2025-02-18 Impove License Plate Detection
2025-02-18 Fix Video Framerate issue [skip ci]
    [video.py]
2025-02-19 Add Filtering to Index
2025-02-19 Add Filtering and Sorting to Index Table
2025-03-06 Add PCB Files
    [Traffic Control System-B_Cu.gbr, Traffic Control System-B_Mask.gbr, Traffic Control System-B_Paste.gbr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]
2025-03-06 Add Gerber Output Files
    [Traffic Control System.kicad_pcb]
2025-03-07 Update PCB
    [Traffic Control System-B_Cu.gbr, Traffic Control System-B_Mask.gbr, Traffic Control System-B_Paste.gbr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]
2025-03-07 Add Traffic Light Stand .step files
    [Traffic Light Stand v6.step, Traffic Light Stand with 2 Lights v9.step]
2025-03-08 Add final PCB Fabrication Files
    [Traffic Control System-B_Cu.gbr, Traffic Control System-B_Mask.gbr, Traffic Control System-B_Paste.gbr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]
2025-03-10 Client Changes [skip ci]
    [deviceControl.py]
2025-03-10 Update Device Control [skip ci]
    [deviceControl.py]
2025-03-10 Fix Colour Case Issue
2025-03-10 Add Buzzers and Revise Buttons [skip ci]
    [deviceControl.py]
2025-03-10 Update Pedestrian Buttons [skip ci]
    [deviceControl.py]
2025-03-10 Set Duy Cycle to 20% [skip ci]
    [deviceControl.py]
2025-03-10 Fix code issues [skip ci]
    [deviceControl.py]
2025-03-10 Update Buzzer and Pedestrian Logic [skip ci]
    [deviceControl.py]
2025-03-11 Improve Buzzer Initialization [skip ci]
    [deviceControl.py]
2025-03-11 Improve Buzzer Timings [skip ci]
    [deviceControl.py]
2025-03-11 Add Button and Buzzer Stand
    [Button and Buzzer stand v10.step]
2025-03-11 Add Pi AI Camera Mount
    [Pi AI Camera Stand v3.step]
2025-03-12 Update CAD Files
    [Button and Buzzer stand v10.step, Button and Buzzer stand.step, Pi AI Camera Stand v3.step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]
2025-03-13 Small Updates [skip ci]
    [Pi AI Camera Stand.step]
2025-03-14 Add pressure sensing [skip ci]
    [deviceControl.py]
2025-03-14 Fix double pin issue [skip ci]
    [deviceControl.py]
2025-03-14 Add Getting Buzzer Volume and adding it tothe config
    [deviceControl.py]
2025-03-14 Add Incident Detection [skip ci]
    [deviceControl.py]
2025-03-14 Improve Violation Detection and Car Waiting Time [skip ci]
    [deviceControl.py, video.py]
2025-03-14 Try to fix FFMpeg Issue [skip ci]
    [deviceControl.py]
2025-03-14 Improve Pedestrian Button Mount
    [Button and Buzzer stand.step]
